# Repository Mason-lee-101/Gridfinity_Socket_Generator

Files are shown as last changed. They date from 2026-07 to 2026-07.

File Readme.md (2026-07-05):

# Gridfinity Socket Holder Generators

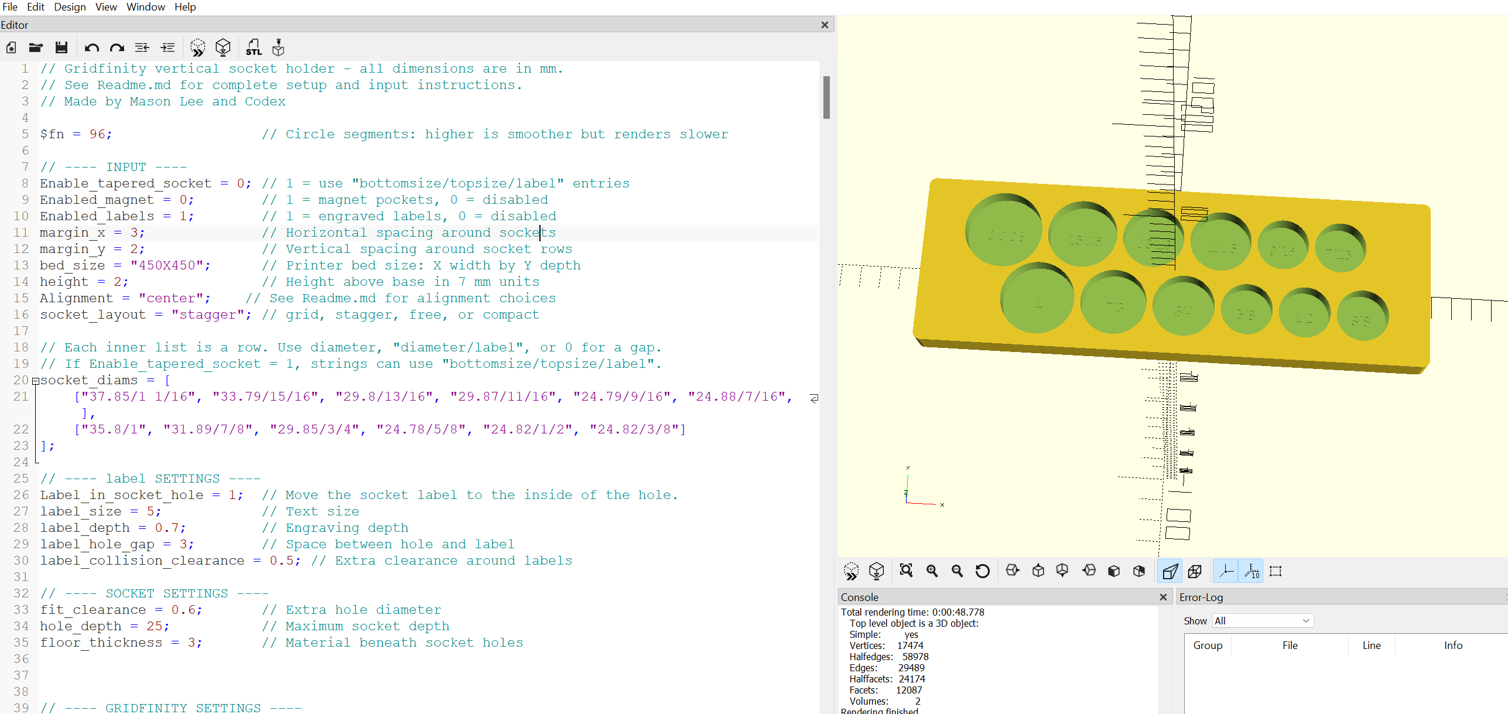
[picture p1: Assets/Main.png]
Generator


A pair of customizable OpenSCAD generators for vertical and horizontal Gridfinity socket holders.

## Requirements
- [OpenSCAD](https://openscad.org/)
- Calipers for measuring socket diameter and length

> Note: I hope it will get hosted somewhere for everyone to use.

## Quick start
1. Measure the sockets that you want to create a holder for.
2. Use Static Site to Adjust the settings and layout of search socket set.
3. Open `Vertical_Socket_generator.scad` or `Horizontal_Socket_generator.scad` in OpenSCAD.
5. Replace the example `socket_diams` / `settings` with the output from the Static Site.
6. Select **File > Export > Export as STL**.

> Note: All measurements in the generator are millimeters.

## How To Measure Sockets
<details>
<summary>Click to expand</summary>

I have added a template CSV file for people to use to measure their sockets.
> Note: you have to use `\` instead of `/` as excel or google sheet will treat the fraction as a date or some other format. 

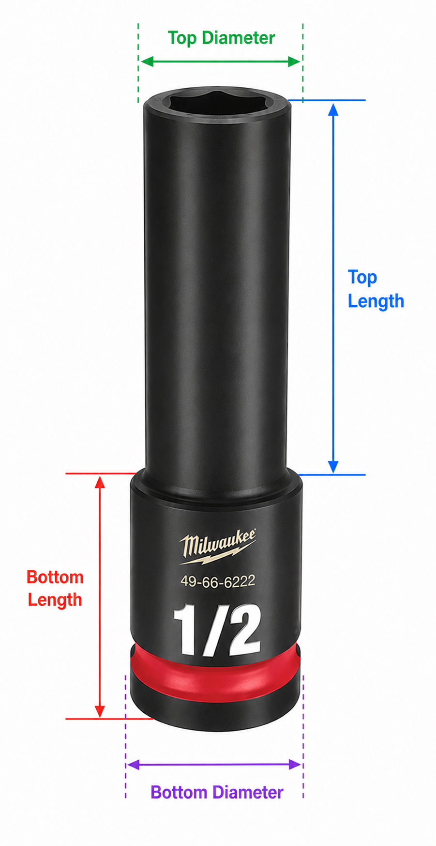
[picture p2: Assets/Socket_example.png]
Socket example


Use calipers and measure in millimeters. Measure the widest outside diameter of the part of the socket that will sit in the holder, not the wrench drive opening.

### For the vertical generator:

1. Measure the socket's outside diameter near the end that goes into the hole.
2. If the socket is tapered, measure both the smaller bottom diameter and the larger top diameter.
3. Use `"diameter/label"` for straight sockets, such as `"19.86/14mm"`.
4. Use `"bottomsize/topsize/label"` for tapered sockets when `Enable_tapered_socket = 1`, such as `"33.5/36/36mm"`.

> Note: For vertical tapered sockets, `bottomsize` is used for the hole diameter. `topsize` is used for layout spacing. Increase `height` or `hole_depth` if the socket needs to sit deeper.

### For the horizontal generator:

1. Measure the socket's outside diameter.
2. Measure the full socket length from end to end.
3. Use `"diameter/length/label"`, such as `"19.86/38/14mm"`.
4. For tapered sockets, measure the bottom diameter, bottom length, top diameter, and top length.
5. Use `"bottom_diameter/bottom_length/top_diameter/top_length/label"` when `Enable_tapered_socket = 1`, such as `"19.86/24/22.5/14/14mm"`.

> Note: If the transition between socket sections is rounded or hard to measure, add a few millimeters to the larger section length so the cradle has enough clearance.

Tips:

- Take a few measurements around the socket and use the largest value.
- If the socket rocks or binds, increase `fit_clearance` slightly.
- If the socket feels too loose, decrease `fit_clearance` slightly.
- Print a small test holder before making a full set.

</details>

## Using Static Site

<details>
<summary>Click to expand</summary>

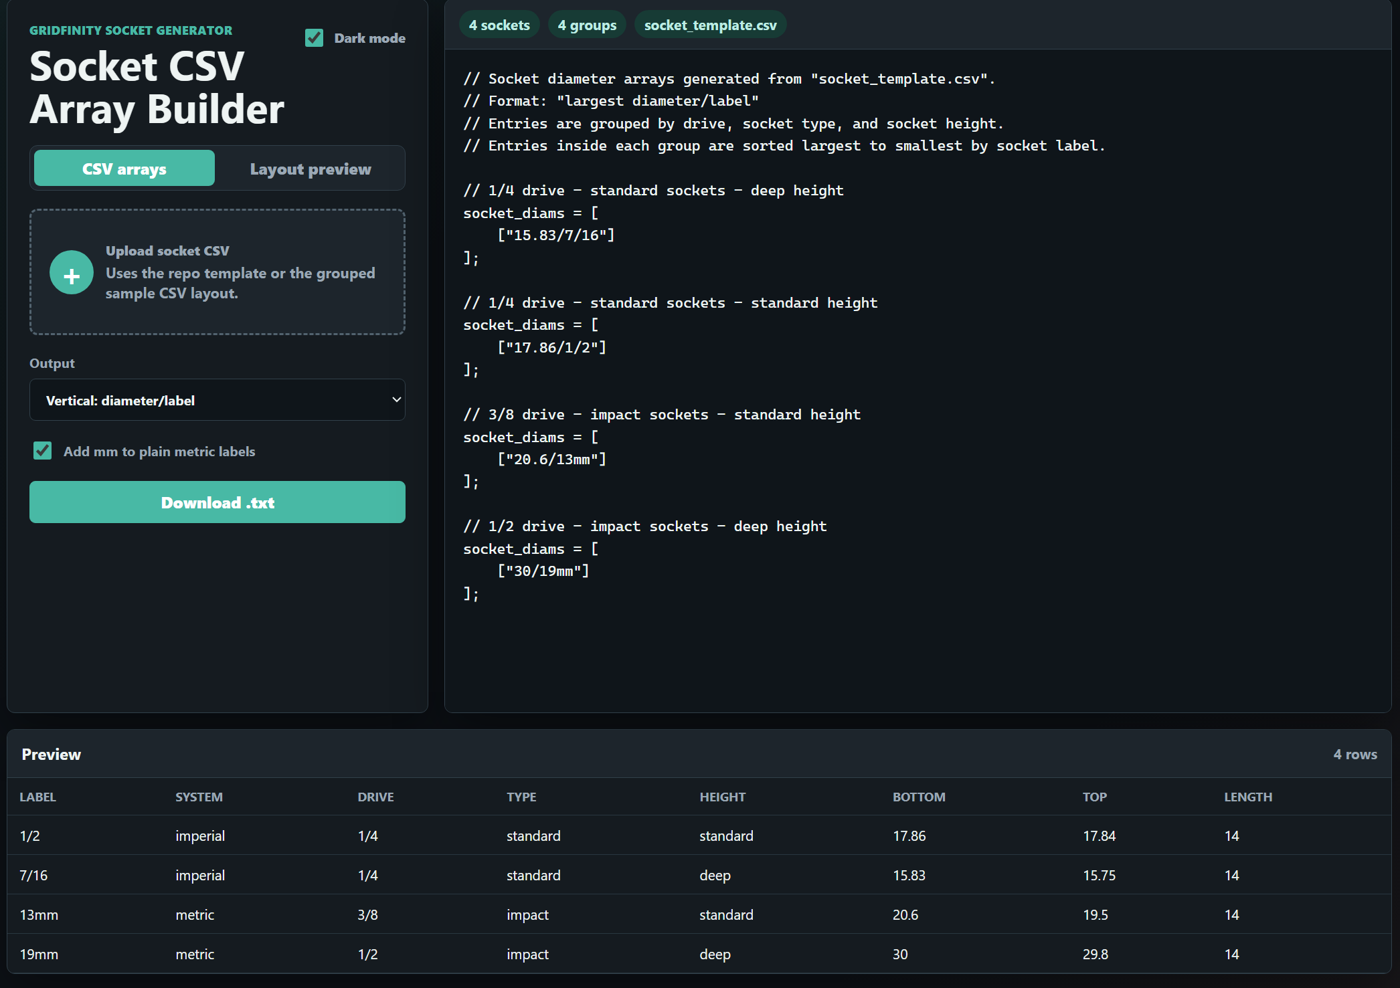
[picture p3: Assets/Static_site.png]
CSV tool web page

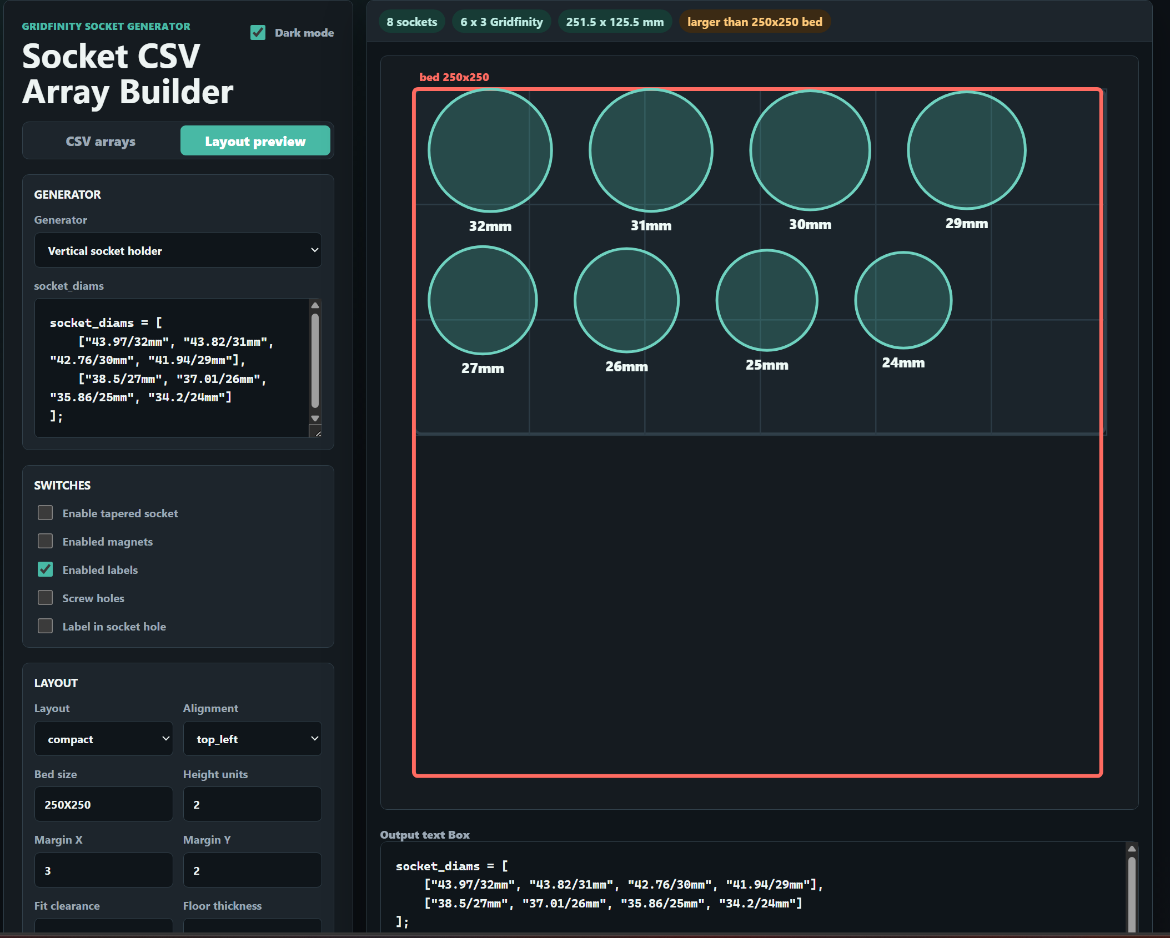
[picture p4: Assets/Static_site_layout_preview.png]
Layout tool web page

The `Site` folder contains a static helper page for converting socket CSV files into `socket_diams` arrays and previewing the Gridfinity layout before opening OpenSCAD.

1. Open `Site/index.html` in a browser.
2. Use **CSV arrays** to upload `socket_template.csv` or a compatible socket CSV.
3. Choose the output format that matches the generator you want to use.
4. Download the generated text or copy the `socket_diams` 
5. Use **Layout preview** to test layout, label, magnet, and screw-hole settings.
6. Copy the replacement text into `Vertical_Socket_generator.scad` or `Horizontal_Socket_generator.scad`.

The static site preserves the socket labels from your CSV. It does not add `mm` to metric labels automatically, so enter labels exactly as you want them engraved.

</details>

## Vertical Socket Generator
<details>
<summary>Click to expand</summary>
`socket_diams` is a list of rows. Rows are placed from top to bottom, and entries within each row are placed from left to right.

```scad
socket_diams = [
    ["19.86/14mm", "17.86/13mm", "16.91/12mm"],
    [27.14, 24.78, 0],
    ["9.19/1/4", "11.1/3/8"]
];
```

- A number such as `27.14` creates a hole for a socket with a 27.14 mm outside diameter.
- A string such as `"19.86/14mm"` creates a 19.86 mm hole with the custom label `14mm`.
- Only the first slash separates the diameter and label, so `"9.19/1/4"` produces the fractional label `1/4`.
- Set `Enable_tapered_socket = 1` for tapered sockets and enter them as `"bottomsize/topsize/label"`, such as `"33.5/36/36mm"`. The socket hole stays straight using `bottomsize`; `topsize` is used for layout spacing.
- A `0` leaves an empty position, which is especially useful in the `grid` layout.
- Add another inner `[ ... ]` list, separated by a comma, to create another row.

</details>

## Horizontal Socket Generator

<details>
<summary>Click to expand</summary>
Open `Horizontal_Socket_generator.scad` to create a holder where sockets lie horizontally. Its normal input format includes both the outside diameter and complete socket length:

```scad
socket_diams = [
    ["19.86/38/14mm", "17.86/36/13mm"],
    ["12.5/50/1/4", 0]
];
```

The format is `"diameter/length/label"`. For example, `"19.86/38/14mm"` means a 19.86 mm diameter socket that is 38 mm long and labeled `14mm`. 

For tapered horizontal sockets, set `Enable_tapered_socket = 1` and use `"bottom_diameter/bottom_length/top_diameter/top_length/label"`:

```scad
socket_diams = [
    ["19.86/24/22.5/14/14mm", "17.86/23/20.2/13/13mm"]
];
```

This creates a two-section cradle: one section for the bottom diameter and length, and one section for the top diameter and length.

Sockets run front-to-back in shallow curved cradles. Adjust `recess_fraction` to change how deeply they sit; values above `0.5` are intentionally rejected to avoid trapping sockets in an undercut.

The horizontal generator supports `"grid"`, `"free"`, and `"compact"` layouts. Compact mode uses the actual cradle widths and lengths to pull rows closer together where adjacent cradles do not overlap.

</details>

## Main settings
<details>
<summary>Click to expand</summary>

### Features

```scad
Enable_tapered_socket = 0;
Enabled_magnet = 0;
Enabled_labels = 0;
Enabled_screw_holes = 0;
```

Use `1` to enable a feature and `0` to disable it. Magnet pockets are added beneath every Gridfinity cell. Labels are engraved beside their matching holes or cradles. Screw holes are added beneath every Gridfinity cell when `Enabled_screw_holes = 1`.
</details>

### Spacing and height
<details>
<summary>Click to expand</summary>

```scad
margin_x = 2;
margin_y = 2;
bed_size = "250X250";
height = 2;
```

`margin_x` controls horizontal spacing between sockets and at the left and right holder edges. `margin_y` controls spacing between socket rows and at the top and bottom edges. Increasing either value can make the holder occupy more Gridfinity cells.

`bed_size` is the printer's usable X-by-Y area in millimeters. Enter it as `"250X250"`. The generator reports an error when the finished Gridfinity footprint is wider or deeper than this size.

`height` is the holder height above the 7 mm base, expressed in 7 mm units:

- `1` = 7 mm above the base
- `2` = 14 mm above the base - **Default**
- `3` = 21 mm above the base

In the vertical generator, when the holder is shorter than the requested `hole_depth`, the holes are shortened automatically to preserve `floor_thickness`.

</details>

### Alignment Settings
<details>
<summary>Click to expand</summary>

```scad
Alignment = "top_left";
```

Available positions are:

- `"top_left"`
- `"top_right"`
- `"center_left"`
- `"center"`
- `"center_right"`
- `"bottom_left"`
- `"bottom_right"`

Alignment positions the complete socket layout inside the Gridfinity-sized holder.

### Layout modes

```scad
socket_layout = "grid";
```

- `"grid"` gives every socket an equally sized position based on the largest socket. Use it for straight, evenly aligned rows and columns.

```text
Row 1:  O   O   O   O
Row 2:  O   O   O   O
Row 3:  O   O   O   O
Row 4:  O   O   O   O
```

- `"stagger"` is available in the vertical generator. It shifts every other row by half of the largest socket pitch and reduces row spacing where the sockets can nest without touching.

```text
Row 1:  O   O   O   O
Row 2:    O   O   O   O
Row 3:  O   O   O   O
Row 4:    O   O   O   O
```

- `"free"` uses each socket's actual width while retaining normal row spacing. Rows stay straight, but small sockets do not consume the same width as large sockets.

```text
Row 1:  O     O    O
Row 2:  O  O      O
Row 3:  O    O  O
```

- `"compact"` packs sockets and rows tightly and accounts for label clearance. This is usually the smallest layout when you want the generator to remove unused space.

```text
Row 1:  O     O    O
Row 2:  O  O      O
Row 3:   O    O  O
```
</details>

## Socket and label Settings
<details>
<summary>Click to expand</summary>

```scad
fit_clearance = 0.6;
hole_depth = 25;
floor_thickness = 3;

label_size = 5;
label_depth = 0.7;
Label_in_socket_hole = 0; // Vertical generator
label_rotation = 0; // Label rotation
Label_in_socket_cradle = 0; // Horizontal generator
label_cradle_scale = 0.75; // Horizontal inside-cradle label size
label_cradle_pocket_margin = 1; // Horizontal pocket extra size
label_cradle_pocket_depth = 1.2; // Horizontal flat label pocket
label_hole_gap = 3;    // Vertical generator
label_socket_gap = 3;  // Horizontal generator
label_collision_clearance = 0.5;
```

- Increase `fit_clearance` if sockets fit too tightly; decrease it if they are too loose.
- `hole_depth` is the maximum vertical socket insertion depth.
- `floor_thickness` is the solid material left beneath each socket.
- The label settings control text size, engraving depth, socket-to-label spacing, and label collision clearance.
- In the vertical generator, set `Label_in_socket_hole = 1` to engrave labels in the bottom of each socket hole instead of beside the hole.
- Use `label_rotation` to rotate labels. In the horizontal generator, it controls both outside labels and inside-cradle labels. `0`, `90`, `180`, and `270` degrees are layout-aware.
- In the horizontal generator, set `Label_in_socket_cradle = 1` to engrave labels in the bottom of each socket cradle instead of beside the cradle.
- Horizontal inside-cradle labels use a flat rectangular pocket controlled by `label_cradle_pocket_depth`.
- The flat pocket is `label_cradle_pocket_margin` larger than the largest rotated label in the holder.
- Use `label_cradle_scale` to make horizontal inside-cradle labels smaller or larger inside the flat pocket.
- When `Label_in_socket_hole = 1`, tiny socket holes automatically reduce the engraved text size so the label stays inside the hole. `label_size` is still the maximum text size.
- When `Label_in_socket_cradle = 1`, tiny socket cradles automatically reduce the engraved text size so the label stays inside the cradle. `label_size` is still the maximum text size.

Print a small test holder before generating a large set, since socket measurements and printer tolerances vary.
</details>

## Advanced Gridfinity Settings
<details>
<summary>Click to expand</summary>

These values normally do not need changing. They define the base profile and optional bottom holes used by both generators.

```scad
grid = 42;
base_h = 7;
base_profile_h = 4.75;
base_top = 41.5;
base_bottom = 35.6;
base_r_top = 3.75;
base_r_bottom = 0.8;

magnet_d = 6.2;
magnet_h = 2.2;
Enabled_screw_holes = 0;
screw_d = 3.2;
screw_h = 7;
hole_from_cell_edge = 8;
```

- `grid` is the 42 mm Gridfinity cell pitch.
- The base dimensions and radii define the tapered Gridfinity foot profile.
- `magnet_d` and `magnet_h` set the optional magnet-pocket size.
- Set `Enabled_screw_holes` to `1` to add screw holes; `screw_d` and `screw_h` set their size.
- `hole_from_cell_edge` positions magnet and screw-hole centers inward from each cell edge.
</details>

## Render Quality Settings
<details>
<summary>Click to expand</summary>

```scad
$fn = 96;
```

This is the number of segments OpenSCAD uses to approximate circles. Higher values produce smoother holes but take longer to render. `48` is useful for faster previews, while `96` is a good final-quality setting.
</details>

## Project files

- `Vertical_Socket_generator.scad` - vertical socket-hole generator using diameter and label inputs
- `Horizontal_Socket_generator.scad` - horizontal socket-cradle generator using diameter, length, and label inputs
- `Site/index.html` - static CSV converter and layout preview helper
- `socket_template.csv` - starter CSV for measuring and organizing sockets

## License

This project is licensed under the [MIT License](LICENSE).

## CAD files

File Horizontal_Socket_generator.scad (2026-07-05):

// Gridfinity flat socket holder
// Sockets lie horizontally in curved cradles. Everything is in mm.
// Made by Mason Lee and Codex


// Each inner list is a row. Use "diameter/length/label" or 0 for a gap.
// If Enable_tapered_socket = 1, strings can use
// "bottom_diameter/bottom_length/top_diameter/top_length/label".
socket_diams = [
    ["19.86/38/14mm", "17.86/36/13mm", "16.91/35/12mm"],
    ["15.85/34/11mm", "13.96/32/10mm", 0]
];


// ---- INPUT ----
// Set switches to 1 to enable them or 0 to disable them.
$fn = 96;                  // Circle segments: higher is smoother but renders slower
Enable_tapered_socket = 0; // 1 = use "bottom_d/bottom_l/top_d/top_l/label" entries
Enabled_magnet = 0;        // Add four magnet pockets beneath every grid cell
Enabled_labels = 1;        // Engrave each socket's label near its cradle
Enabled_screw_holes = 0;   // 1 = screw pockets, 0 = disabled
margin_x = 2;              // Horizontal space around and between cradles
margin_y = 2;              // Vertical space around cradle rows
bed_size = "250X250";      // Printer bed size: X width by Y depth
height = 2;                // Holder height above the base, in 7 mm units
Alignment = "top_left";    // top_left, top_right, center_left, center, center_right, bottom_left, or bottom_right
socket_layout = "grid";    // grid, free, or compact

//  ---- Label SETTINGS ----
Label_in_socket_cradle = 0; // Move the socket label to the inside of the cradle.
label_rotation = 0;        // Rotate labels in degrees. 0, 90, 180, and 270
label_cradle_scale = 0.75; // Shrink inside-cradle labels for the flat pocket.
label_cradle_pocket_margin = 3; // Pocket is this much larger than the label.
label_cradle_pocket_depth = 1.2; // Depth of the flat-bottom label pocket.
label_size = 5;            // OpenSCAD text size in mm
label_depth = 0.7;         // Label engraving depth in mm
label_socket_gap = 3;      // Space in mm between a cradle end and its label
label_collision_clearance = 0.5; // Extra clearance around labels

// ---- SOCKET CRADLE SETTINGS ----
fit_clearance = 0.6;       // Extra mm added to the cradle diameter
length_clearance = 1;      // Extra total mm added to the cradle length
recess_fraction = 0.40;    // Portion of socket diameter recessed into the top
floor_thickness = 3;       // Solid material left below the deepest cradle


// ---- GRIDFINITY SETTINGS ----
grid = 42;                 // Gridfinity cell pitch in mm

base_h = 7;                // Total Gridfinity base height in mm
base_profile_h = 4.75;     // Height of the tapered foot profile
base_bridge_h = base_h - base_profile_h;

base_top = 41.5;           // Width of each foot at the top
base_bottom = 35.6;        // Width of each foot at the bottom
base_r_top = 3.75;         // Top foot/body corner radius
base_r_bottom = 0.8;       // Bottom foot corner radius

magnet_d = 6.2;            // Magnet-pocket diameter
magnet_h = 2.2;            // Magnet-pocket depth

screw_d = 3.2;             // Screw-hole diameter
screw_h = 7;               // Screw-hole depth

hole_from_cell_edge = 8;   // Magnet/screw center distance from cell edges

// ---- DERIVED ----
rows = len(socket_diams);
cols = max([for (row = socket_diams) len(row)]);

layout_max_d = max([
    for (row = socket_diams)
        for (entry = row)
            if (socket_diameter(entry) > 0)
                socket_diameter(entry) + fit_clearance
]);

layout_max_l = max([
    for (row = socket_diams)
        for (entry = row)
            if (socket_diameter(entry) > 0)
                socket_length(entry) + length_clearance
]);

layout_max_w = max([
    for (row = socket_diams)
        for (entry = row)
            if (socket_diameter(entry) > 0)
                entry_width(entry)
]);

grid_pitch_x = layout_max_w + margin_x;
grid_pitch_y = layout_max_l + margin_y + label_band();

required_x = socket_layout == "grid"
    ? cols * layout_max_w + (cols + 1) * margin_x
    : max([for (r = [0 : rows - 1]) row_width(r)]);

required_y = socket_layout == "grid"
    ? rows * layout_max_l + (rows + 1) * margin_y +
        rows * label_band()
    : socket_layout == "compact"
        ? compact_required_y()
        : list_sum([for (r = [0 : rows - 1]) row_height(r)]) +
            margin_y;

base_cols = max(1, ceil((required_x + 0.5) / grid));
base_rows = max(1, ceil((required_y + 0.5) / grid));

body_x = base_cols * grid - 0.5;
body_y = base_rows * grid - 0.5;

bed_separator = bed_separator_index(bed_size);
bed_x = bed_separator > 0
    ? parse_bed_number(bed_size, 0, bed_separator)
    : 0;
bed_y = bed_separator > 0 && bed_separator < len(bed_size) - 1
    ? parse_bed_number(bed_size, bed_separator + 1, len(bed_size))
    : 0;

holder_h = height * 7;
total_h = base_h + holder_h;

assert(holder_h > floor_thickness,
    "height must leave room for the floor_thickness");
assert(
    is_string(bed_size) && bed_separator > 0 &&
        bed_separator < len(bed_size) - 1 &&
        valid_bed_number(bed_size, 0, bed_separator) &&
        valid_bed_number(bed_size, bed_separator + 1, len(bed_size)) &&
        bed_x > 0 && bed_y > 0,
    "bed_size must use the format 250X250"
);
assert(
    body_x <= bed_x && body_y <= bed_y,
    str("Holder footprint ", body_x, "X", body_y,
        " mm exceeds bed_size ", bed_size)
);
assert(recess_fraction > 0 && recess_fraction <= 0.5,
    "recess_fraction must be greater than 0 and no more than 0.5");
assert(!Label_in_socket_cradle ||
    floor_thickness > label_cradle_pocket_depth + label_depth,
    "floor_thickness must be greater than label_cradle_pocket_depth plus label_depth");
assert(
    Alignment == "top_left" || Alignment == "top_right" ||
    Alignment == "center_left" || Alignment == "center" ||
    Alignment == "center_right" || Alignment == "bottom_left" ||
    Alignment == "bottom_right",
    "Unknown Alignment value"
);
assert(
    socket_layout == "grid" || socket_layout == "free" ||
    socket_layout == "compact",
    "socket_layout must be grid, free, or compact"
);

// ---- BUILD ----
difference() {
    union() {
        gridfinity_base(base_cols, base_rows);

        translate([0, 0, base_h])
            rounded_box(body_x, body_y, holder_h, base_r_top);
    }

    socket_cradles();

    if (Enabled_labels)
        engraved_labels();

    if (Enabled_magnet)
        gridfinity_magnet_holes(base_cols, base_rows);

    if (Enabled_screw_holes)
        gridfinity_screw_holes(base_cols, base_rows);
}

// ---- HORIZONTAL SOCKET CRADLES ----
module socket_cradles() {
    for (r = [0 : rows - 1]) {
        for (c = [0 : len(socket_diams[r]) - 1]) {
            entry = socket_diams[r][c];
            d = socket_diameter(entry);

            if (d > 0) {
                total_l = socket_length(entry) + length_clearance;
                top_l = socket_top_length(entry) +
                    (is_tapered_entry(entry) ? length_clearance / 2 : 0);
                bottom_l = socket_bottom_length(entry) +
                    (is_tapered_entry(entry) ? length_clearance / 2 : 0);
                y_start = socket_y(r) + total_l / 2;

                if (is_tapered_entry(entry)) {
                    cradle_segment(
                        socket_x(r, c),
                        y_start,
                        bottom_l,
                        socket_bottom_diameter(entry)
                    );
                    cradle_segment(
                        socket_x(r, c),
                        y_start - bottom_l,
                        top_l,
                        socket_top_diameter(entry)
                    );
                } else {
                    cradle_segment(
                        socket_x(r, c),
                        y_start,
                        total_l,
                        d
                    );
                }
            }
        }
    }
}

module cradle_segment(x, y_start, segment_l, segment_d) {
    cradle_d = segment_d + fit_clearance;
    recess = effective_recess_d(segment_d);

    // The cylinder axis runs front-to-back along the Y direction.
    translate([
        x,
        y_start,
        total_h + cradle_d / 2 - recess
    ])
        rotate([90, 0, 0])
            cylinder(h = segment_l, d = cradle_d);
}

// ---- GRIDFINITY BASE ----
module gridfinity_base(nx, ny) {
    union() {
        for (x = [0 : nx - 1]) {
            for (y = [0 : ny - 1]) {
                translate([
                    (x - (nx - 1) / 2) * grid,
                    (y - (ny - 1) / 2) * grid,
                    0
                ])
                    gridfinity_foot();
            }
        }

        translate([0, 0, base_profile_h])
            rounded_box(body_x, body_y, base_bridge_h, base_r_top);
    }
}

module gridfinity_foot() {
    union() {
        rounded_hull_box(
            base_bottom, base_bottom,
            37.2, 37.2,
            0.8, base_r_bottom, 1.6
        );

        translate([0, 0, 0.8])
            rounded_box(37.2, 37.2, 1.8, 1.6);
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

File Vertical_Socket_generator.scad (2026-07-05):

// Gridfinity vertical socket holder - all dimensions are in mm.
// See Readme.md for complete setup and input instructions.
// Made by Mason Lee and Codex


// Each inner list is a row. Use diameter, "diameter/label", or 0 for a gap.
// If Enable_tapered_socket = 1, strings can use "bottomsize/topsize/label".
socket_diams = [
    ["43.97/32mm", "43.82/31mm", "42.76/30mm", "41.94/29mm", "41.01/28mm"],
    ["38.5/27mm", "37.01/26mm", "35.86/25mm", "34.2/24mm", "33.88/23mm", "31.83/22mm"],
    ["29.98/21mm", "29.92/17mm", "29.89/19mm", "29.89/20mm", "29.85/18mm", "24.88/14mm"],
    ["24.86/11mm", "24.85/16mm", "24.84/8mm", "24.83/13mm", "24.83/10mm", "24.82/9mm", "24.82/12mm", "24.82/15mm"]
];



// ---- INPUT ----
$fn = 96;                  // Circle segments: higher is smoother but renders slower
Enable_tapered_socket = 0; // 1 = use "bottomsize/topsize/label" entries
Enabled_magnet = 0;        // 1 = magnet pockets, 0 = disabled
Enabled_labels = 1;        // 1 = engraved labels, 0 = disabled
Enabled_screw_holes = 0;   // 1 = screw pockets, 0 = disabled
margin_x = 3;              // Horizontal spacing around sockets
margin_y = 2;              // Vertical spacing around socket rows
bed_size = "250X250";      // Printer bed size: X width by Y depth
height = 2;                // Height above base in 7 mm units
Alignment = "top_left";    // See Readme.md for alignment choices
socket_layout = "compact"; // grid, stagger, free, or compact

// ---- label SETTINGS ----
Label_in_socket_hole = 0;  // Move the socket label to the inside of the hole.
label_rotation = 0;        // Rotate labels in degrees. 0, 90, 180, and 270
label_size = 5;            // Text size
label_depth = 0.7;         // Engraving depth
label_hole_gap = 3;        // Space between hole and label
label_collision_clearance = 0.5; // Extra clearance around labels

// ---- SOCKET SETTINGS ----
fit_clearance = 0.6;       // Extra hole diameter
hole_depth = 25;           // Maximum socket depth
floor_thickness = 3;       // Material beneath socket holes



// ---- GRIDFINITY SETTINGS ----
grid = 42;                 // Gridfinity cell pitch

base_h = 7;                // Base height
base_profile_h = 4.75;     // Foot-profile height
base_bridge_h = base_h - base_profile_h;

base_top = 41.5;           // Foot width at top
base_bottom = 35.6;        // Foot width at bottom

base_r_top = 3.75;         // Top corner radius
base_r_bottom = 0.8;       // Bottom corner radius

magnet_d = 6.2;            // Magnet-pocket diameter
magnet_h = 2.2;            // Magnet-pocket depth

screw_d = 3.2;             // Screw-hole diameter
screw_h = 7;               // Screw-hole depth

hole_from_cell_edge = 8;   // Hole-center distance from cell edges

// ---- DERIVED ----
rows = len(socket_diams);
cols = max([for (r = socket_diams) len(r)]);

// Pack sockets by their actual diameters and margins, then round the finished
// bin up to whole Gridfinity cells.
layout_max_d = max([
    for (row = socket_diams)
        for (entry = row)
            if (socket_diameter(entry) > 0)
                socket_diameter(entry) + fit_clearance
]);
layout_max_w = max([
    for (row = socket_diams)
        for (entry = row)
            if (socket_diameter(entry) > 0)
                entry_width(entry)
]);
grid_pitch_x = layout_max_w + margin_x;
grid_pitch_y = layout_max_d + margin_y + label_band();

required_x = socket_layout == "grid"
    ? cols * layout_max_w + (cols + 1) * margin_x
    : socket_layout == "stagger"
        ? max([for (r = [0 : rows - 1]) stagger_row_width(r)])
        : max([for (r = [0 : rows - 1]) row_width(r)]);
required_y = socket_layout == "grid"
    ? rows * layout_max_d + (rows + 1) * margin_y +
        rows * label_band()
    : socket_layout == "stagger"
        ? stagger_required_y()
        : list_sum([for (r = [0 : rows - 1]) row_height(r)]) + margin_y;
base_cols = max(1, ceil((required_x + 0.5) / grid));
base_rows = max(1, ceil((required_y + 0.5) / grid));

body_x = base_cols * grid - 0.5;
body_y = base_rows * grid - 0.5;

bed_separator = bed_separator_index(bed_size);
bed_x = bed_separator > 0
    ? parse_bed_number(bed_size, 0, bed_separator)
    : 0;
bed_y = bed_separator > 0 && bed_separator < len(bed_size) - 1
    ? parse_bed_number(bed_size, bed_separator + 1, len(bed_size))
    : 0;

holder_h = height * 7;
total_h = base_h + holder_h;
effective_hole_depth = min(hole_depth, holder_h - floor_thickness);

assert(holder_h > floor_thickness,
    "height must leave room for the floor_thickness");
assert(
    is_string(bed_size) && bed_separator > 0 &&
        bed_separator < len(bed_size) - 1 &&
        valid_bed_number(bed_size, 0, bed_separator) &&
        valid_bed_number(bed_size, bed_separator + 1, len(bed_size)) &&
        bed_x > 0 && bed_y > 0,
    "bed_size must use the format 250X250"
);
assert(
    body_x <= bed_x && body_y <= bed_y,
    str("Holder footprint ", body_x, "X", body_y,
        " mm exceeds bed_size ", bed_size)
);
assert(
    Alignment == "top_left" || Alignment == "top_right" ||
    Alignment == "center_left" || Alignment == "center" ||
    Alignment == "center_right" || Alignment == "bottom_left" ||
    Alignment == "bottom_right",
    "Unknown Alignment value"
);
assert(
    socket_layout == "grid" || socket_layout == "stagger" ||
    socket_layout == "free" || socket_layout == "compact",
    "Unknown socket_layout value"
);


// ---- BUILD ----
difference() {
    union() {
        gridfinity_base(base_cols, base_rows);

        translate([0, 0, base_h])
            rounded_box(body_x, body_y, holder_h, base_r_top);
    }

    socket_holes();

    if (Enabled_labels)
        engraved_labels();

    if (Enabled_magnet)
        gridfinity_magnet_holes(base_cols, base_rows);

    if (Enabled_screw_holes)
        gridfinity_screw_holes(base_cols, base_rows);
}


// ---- SOCKET HOLES ----
module socket_holes() {
    for (r = [0 : rows - 1]) {
        for (c = [0 : len(socket_diams[r]) - 1]) {
            entry = socket_diams[r][c];
            d = socket_diameter(entry);

            if (d > 0) {
                translate([
                    socket_x(r, c),
                    socket_y(r, c),
                    total_h - effective_hole_depth
                ])
                    cylinder(
                        h = effective_hole_depth + 0.25,
                        d = socket_hole_diameter(entry) + fit_clearance
                    );
            }
        }
    }
}





// ---- CORRECTED GRIDFINITY BASE ----
module gridfinity_base(nx, ny) {
    union() {
        // One Gridfinity foot per cell.
        for (x = [0 : nx - 1]) {
            for (y = [0 : ny - 1]) {
                translate([
                    (x - (nx - 1) / 2) * grid,
                    (y - (ny - 1) / 2) * grid,
                    0
                ])
                    gridfinity_foot();
            }
        }

        // Continuous bridge tying all feet together.
        translate([0, 0, base_profile_h])
            rounded_box(body_x, body_y, base_bridge_h, base_r_top);
    }
}


// One 1x1 Gridfinity bottom foot.
// Profile:
// z 0.00  : 35.6 mm bottom
// z 0.80  : first 45° chamfer
// z 2.60  : vertical wall section
// z 4.75  : second 45° chamfer to 41.5 mm top
module gridfinity_foot() {
    union() {
        rounded_hull_box(
            base_bottom,
            base_bottom,
            37.2,
            37.2,
            0.8,
            base_r_bottom,
            1.6
        );

        translate([0, 0, 0.8])
            rounded_box(37.2, 37.2, 1.8, 1.6);

        translate([0, 0, 2.6])
            rounded_hull_box(
                37.2,
                37.2,
                base_top,
                base_top,
                2.15,
                1.6,
                base_r_top
            );
    }
}


// ---- MAGNET / SCREW HOLES ----
module gridfinity_magnet_holes(nx, ny) {
    for (x = [0 : nx - 1]) {
        for (y = [0 : ny - 1]) {
            cx = (x - (nx - 1) / 2) * grid;
            cy = (y - (ny - 1) / 2) * grid;

            for (sx = [-1, 1]) {
                for (sy = [-1, 1]) {
                    translate([
                        cx + sx * (base_top / 2 - hole_from_cell_edge),
                        cy + sy * (base_top / 2 - hole_from_cell_edge),
                        -0.05
                    ])
                        cylinder(h = magnet_h + 0.1, d = magnet_d);
                }
            }
        }
    }
}

module gridfinity_screw_holes(nx, ny) {
    for (x = [0 : nx - 1]) {
        for (y = [0 : ny - 1]) {
            cx = (x - (nx - 1) / 2) * grid;
            cy = (y - (ny - 1) / 2) * grid;
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

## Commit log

2026-06-26 Add support for tapered sockets LESS AI SLOP in readme
    [Vertical_Socket_generator.scad]
2026-06-30 Added better label clearances
    [Horizontal_Socket_generator.scad, Vertical_Socket_generator.scad]
2026-07-02 Added support for having labels in the socket hole
    [Horizontal_Socket_generator.scad, Vertical_Socket_generator.scad]
2026-07-02 added tapered to horizontal generator added pictures added a how to measure sockets added Socket csv template
    [Horizontal_Socket_generator.scad, socket_template.csv]
2026-07-03 Fix Labels with really small sockets holes added labels inside of cradle for Horizontal socket added label rotation option
    [Horizontal_Socket_generator.scad, Vertical_Socket_generator.scad]
2026-07-03 Fixed labels rotations
    [Horizontal_Socket_generator.scad, Vertical_Socket_generator.scad]
2026-07-05 Update the Screw hole option
    [Horizontal_Socket_generator.scad, Vertical_Socket_generator.scad]
2026-07-05 Added a local site for converting the template CSV file into an out and a preview of layout updated readme about screw hole and site usage
